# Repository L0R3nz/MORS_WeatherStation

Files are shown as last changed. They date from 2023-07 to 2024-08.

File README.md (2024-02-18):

# M.O.R.S.
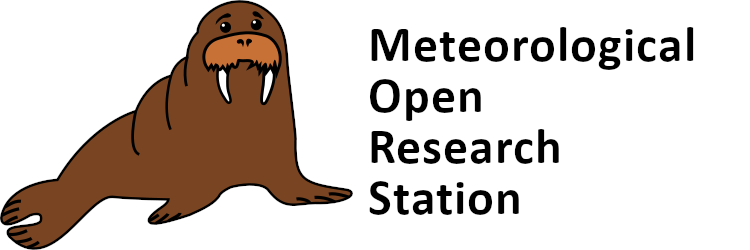
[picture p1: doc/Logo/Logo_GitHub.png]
M.O.R.S.


This weather station is a passion-driven open-source project aimed at providing accurate monitoring of atmospheric conditions. Please note that as a hobby project, it may contain errors or limitations in functionality. However, I will do my best to continuously improving and refining the station's capabilities.

# Links
1. [Project Requirements](doc/Requirements.md)
2. [Sensors Evaluation](doc/Sensors.md)
3. [Hardware Documentation](doc/Hardware.md)

______________________________________________________
M.O.R.S project is based on opensource [tools](doc/Tools.md)

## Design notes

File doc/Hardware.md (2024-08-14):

# Hardware
## 1. EnvironmentSensors
### Jumper list
|Jumper	|Function																	|
|---|---|
|JP1	|Set BME680 Address <br>0x76 - Open <br>0x77 - Closed						|
|JP2	|Set LPS22HB Address <br>0x5C - Open <br>0x5D - Closed						|
|JP3	|Bridge EXT_3V3 signal from connector J1 <br>to 3V3 signal of J2 connector	|

### Useful Files
- [iBom File](/../master/Hardware/1.EnvironmentSensors/Kicad/doc/ibom/) - interactive file which help you while soldering 
- [Schematic File](/../master/Hardware/1.EnvironmentSensors/Kicad/doc/schematic/EnvironmentSensors.pdf)
- [Stencil Holder](/../master/Hardware/Tools/StencilHolder/)

Front side of PCB
![PCB_KiCad_EnvironmentSensors_Front]

Back side of PCB
![PCB_KiCad_EnvironmentSensors_Back]

Stencil Holder 
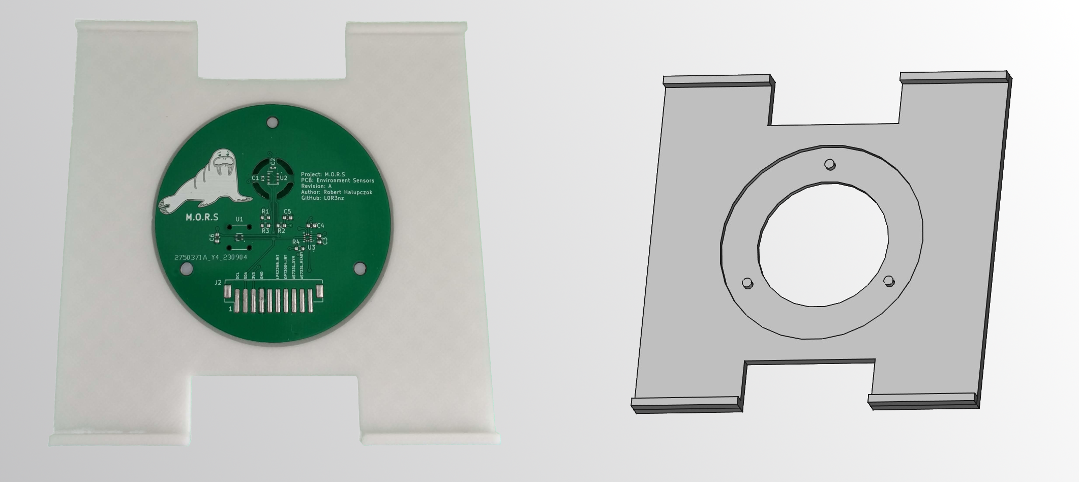
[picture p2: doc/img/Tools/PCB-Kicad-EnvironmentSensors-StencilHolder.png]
PCB_KiCad_EnvironmentSensors_StencilHolder


## 12. LightSensors
### Jumper list
|Jumper	 |Function |
|---|---|
|ADDR1	 |Set OPT3004 Address according to layout description|
|A0 and A1  |Set AS7331 Address according to layout description |

### Useful Files
- [iBom File](/../master/Hardware/2.LightSensors/Kicad/doc/ibom/) - interactive file which help you while soldering 
- [Schematic File](/../master/Hardware/2.LightSensors/Kicad/doc/schematic/LightSensors.pdf)

Front side of PCB
![PCB_KiCad_LightSensors_Front]

Back side of PCB
![PCB_KiCad_LightSensors_Back]

<!-- Images and diagrams -->
[PCB_KiCad_EnvironmentSensors_Front]: 	        img/Hardware/PCB-Kicad-EnvironmentSensors-Front.png
[PCB_KiCad_EnvironmentSensors_Back]: 	        img/Hardware/PCB-Kicad-EnvironmentSensors-Back.png
[PCB_KiCad_EnvironmentSensors_StencilHolder]: 	img/Tools/PCB-Kicad-EnvironmentSensors-StencilHolder.png
[PCB_KiCad_LightSensors_Front]: 	            img/Hardware/PCB-Kicad-LightSensors-Front.png
[PCB_KiCad_LightSensors_Back]: 	                img/Hardware/PCB-Kicad-LightSensors-Back.png

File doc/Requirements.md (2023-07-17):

# Weather Station Project Requirements

The following are the general requirements for the weather station project:

1. The weather station should be designed as an open-source project, allowing for continuous development, customization of functionalities, and integration with other systems.
2. All components used in the weather station should be easily accessible and available for ordinary users to order.
3. The station should be designed with durability and weather resistance in mind, enabling long-term and reliable outdoor use.

## Sensors Requirements

The weather station should accurately measure the following parameters within their specified ranges:

| |Parameter |Unit  |Range |
|:--|:---|:-----|:---|
|1  |Temperature |°C |-40 to 60 |
|2  |Humidity |%RH |0 - 100 |
|3  |Pressure |hPa |800 - 1100|
|4  |Wind Speed |m/s |0 - 50 |
|5  |Wind Direction |rad |0 - 360 |
|6  |Rain Gauge |mm/m² |0 - 100 |
|7  |UV (A/B/C) |μW/cm²|n/a |
|8  |Ambient Light |lux |0 - 200k  |
|9  |Air Quality (PM1 / PM2.5 / PM10) |μg/m³ |0 - 1000  |

## Hardware Requirements

The weather station's hardware should meet the following requirements:

1. Processor and Power Management:
   - The device should be equipped with an energy-efficient processor or microcontroller that enables efficient power management.
   - The power management system should be optimized for minimal energy consumption, allowing for long-term operation on batteries or efficient utilization of available power sources.

2. Wireless Communication:
   - Wireless communication modules such as Wi-Fi, Bluetooth, or LoRa should be optimized for low energy consumption, enabling efficient data transmission with minimal impact on power resources.
   - The device should incorporate power management features for adjusting the transmission frequency and power as needed.

3. Sensors:
   - The selection of sensors should prioritize low energy consumption to minimize the impact on device energy efficiency.
   - Sensors with features like automatic wake-up or energy regulation should be preferred to activate them only when necessary.

4. Power Resource Management:
   - The device should have intelligent power resource management mechanisms, such as sleep mode or automatic shut-off of unused components, to minimize energy consumption during idle periods.
   - The software should include energy optimization algorithms to efficiently utilize power resources in different operational scenarios.

## Enclosure Requirements

The enclosure of the weather station should meet the following specifications:

1. The enclosure should be made of durable and weather-resistant material.
2. It should be sealed to provide protection against moisture, dust, and sun radiation.
3. All enclosure components, including structural elements and fittings, should be 3D-printable for cost-effective manufacturing and customization.

## Additional Requirements

1. The weather station should be designed for future integration with photovoltaic (PV) panels for power supply, though this functionality will not be implemented initially.
2. Remote software updates should be possible to facilitate easy enhancements and bug fixes.

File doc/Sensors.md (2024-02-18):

# Sensor Evaluation 

In following document you will find information regarding sensor planned to use in weather station project.
___

For more accurate results, I plan to use multiple sensors for temperature, humidity, and pressure. All of these sensors will be located on separate PCBs to mitigate the influence of other circuit elements that can generate heat and thereby interfere with the measurements. This sensor board should be located in solar radiation shield to minimize direct sunlight which can heat up the sensors, affecting the accuracy of temperature readings

# Sensors Diagram
SensorDiagram

## 1. Environment Sensors Group

|Sensor |[BME680](Datasheets/BME680.pdf) |[SHT45](Datasheets/SHT4x.pdf)  |[LPS22HB](Datasheets/LPS22HB.pdf)|
|---|---|---|---|
|Temperature |:white_check_mark: |:white_check_mark: |:x: |
|Humidity |:white_check_mark: |:white_check_mark: |:x: |
|Pressure |:white_check_mark: |:x: |:white_check_mark: |
|SPI |:white_check_mark: |:x: |:white_check_mark: |
|I2C |:white_check_mark: |:white_check_mark: |:white_check_mark: |
|Voltage |1.71 - 3.6 |1.08 - 3.6 |1.70 - 3.6 |
|Current Consumption  |12 mA (Active)<br>1 mA (Low Power)<br>90 μA (Ultra Low Power)|2 μA (Average) |3 μA (Average) |

## 2. Light Sensors Group

|Sensor |[AS7331](Datasheets/AS7331.pdf) |[OPT3004](Datasheets/OPT3004.pdf) |
|---|---|---|
|UV (A/B/C) |:white_check_mark: |:x: |
|Ambient Light |:x: |:white_check_mark: |
|SPI |:x: |:x: |
|I2C |:white_check_mark: |:white_check_mark: |
|Voltage |2.7 - 3.6 |1.6 - 3.6
|Current Consumption  |2 mA (Active)<br>970 μA (Standby)<br>1 μA (Power Down) |1.8 μA (Typical)

<!-- ## 3. Wind Sensors Group -->
<!-- ## 4. Rain Sensor Group -->

<!-- Images and diagrams -->
[SensorDiagram]: img/Sensors/Sensors-diagram.svg

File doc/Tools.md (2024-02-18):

# Tools used in project
## [KiCad](https://www.kicad.org/)
```
Application: KiCad x64 on x64

Version: 7.0.6, release build

Libraries:
	wxWidgets 3.2.2
	FreeType 2.12.1
	HarfBuzz 6.0.0
	FontConfig 2.14.1
	libcurl/7.88.1-DEV Schannel zlib/1.2.13

Platform: Windows 10 (build 19045), 64-bit edition, 64 bit, Little endian, wxMSW

Build Info:
	Date: Jul  6 2023 04:56:45
	wxWidgets: 3.2.2 (wchar_t,wx containers)
	Boost: 1.81.0
	OCC: 7.6.3
	Curl: 7.88.1-DEV
	ngspice: 40
	Compiler: Visual C++ 1936 without C++ ABI

Build settings:
	KICAD_SPICE=ON
```
### Installed addons:

|Addon |Version |
|---|---|
|__Espressif KiCad Library__ |[2.0.1](https://github.com/espressif/kicad-libraries/releases/tag/2.0.1) |
|__Fabrication Toolkit__ |[3.0.0](https://github.com/bennymeg/JLC-Plugin-for-KiCad/releases/tag/3.0.0) |
|__Interactive Html Bom__ |[2.7.0](https://github.com/openscopeproject/InteractiveHtmlBom/releases/tag/v2.7.0)|
|__Archive 3D Models__ |[1.0.10](https://github.com/MitjaNemec/Archive3DModels/releases/tag/1.0.10) |

## [FreeCad](https://www.freecad.org/)
```
OS: Windows 10 Version 2009
Word size of FreeCAD: 64-bit
Version: 0.20.2.29603 (Git)
Build type: Release
Branch: releases/FreeCAD-0-20
Hash: 930dd9a76203a3260b1e6256c70c1c3cad8c5cb8
Python 3.8.10, Qt 5.15.2, Coin 4.0.1, Vtk 8.2.0, OCC 7.6.3
Locale: Polish/Poland (pl_PL)
Installed mods: 
  * A2plus 0.4.60n
  * kicadStepUpMod 10.19.4
```

## [Inkscape](https://inkscape.org/)
```
Inkscape 1.2.2 (732a01da63, 2022-12-09)
```

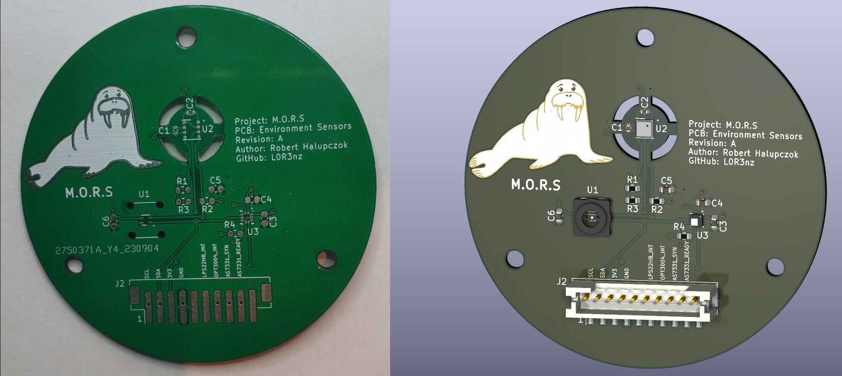
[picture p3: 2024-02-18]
doc/img/Hardware/PCB-Kicad-EnvironmentSensors-Front.png

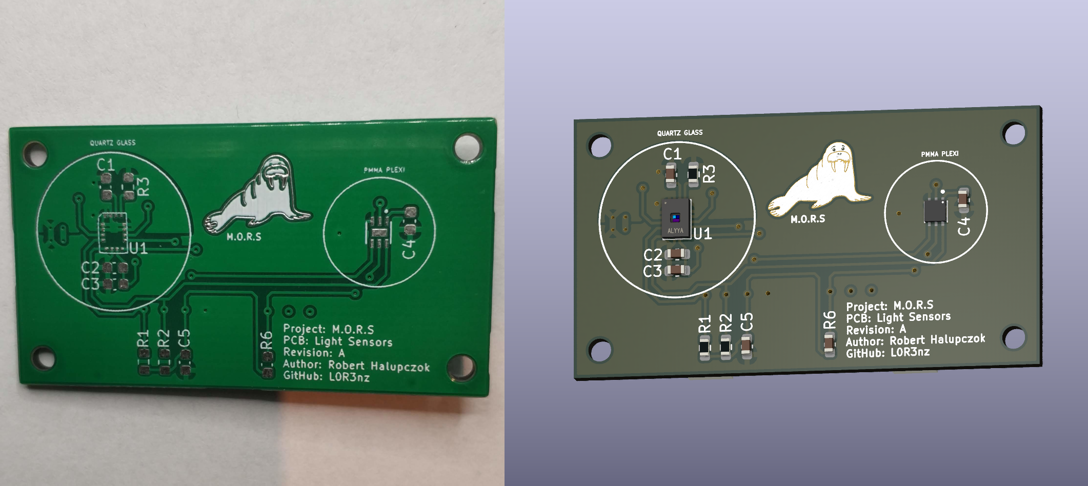
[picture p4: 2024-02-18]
doc/img/Hardware/PCB-Kicad-LightSensors-Front.png

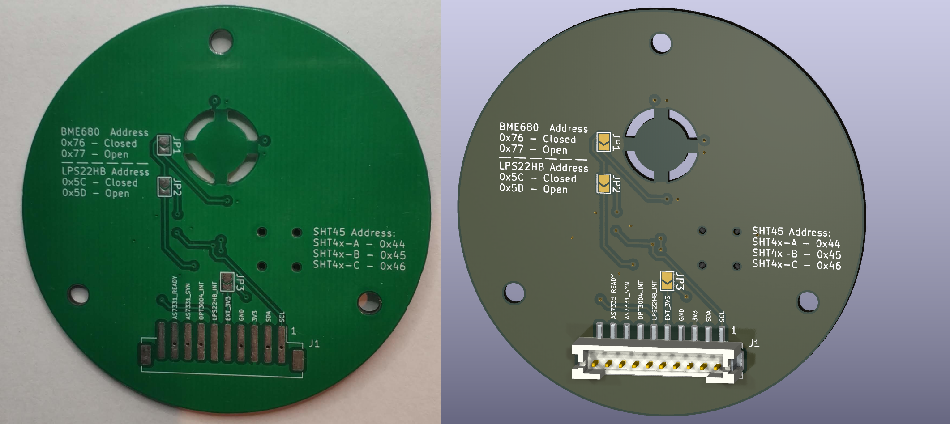
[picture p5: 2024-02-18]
doc/img/Hardware/PCB-Kicad-EnvironmentSensors-Back.png

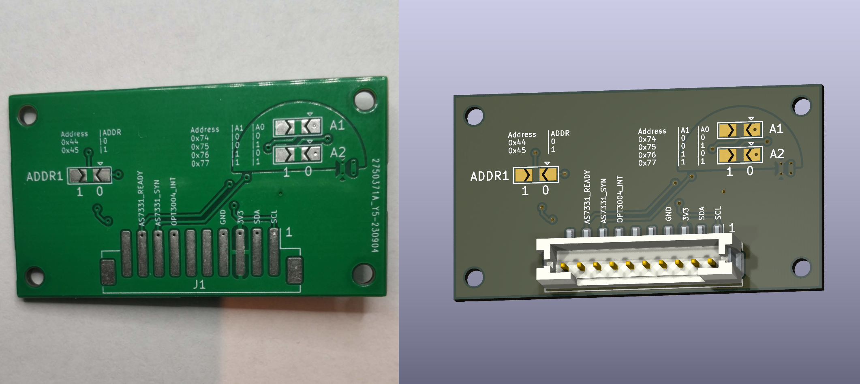
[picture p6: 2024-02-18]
doc/img/Hardware/PCB-Kicad-LightSensors-Back.png

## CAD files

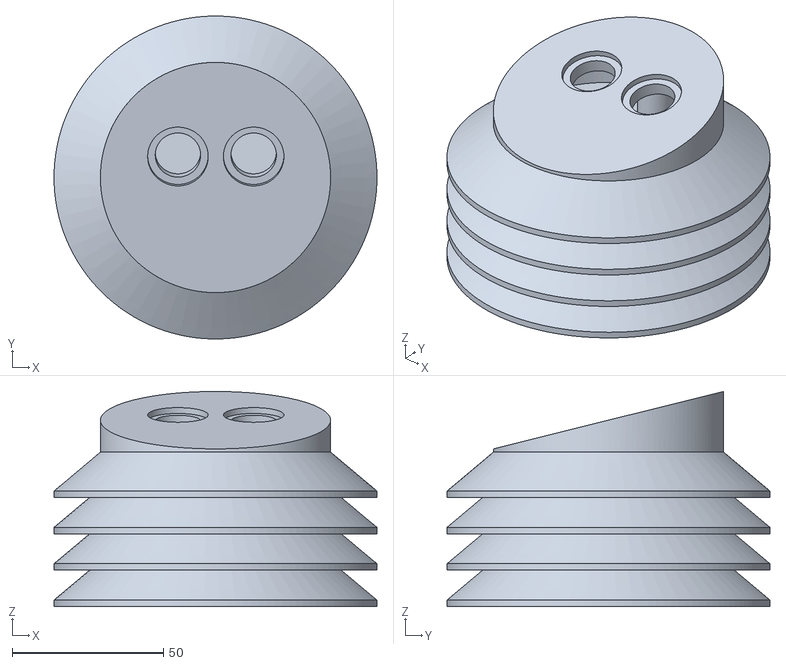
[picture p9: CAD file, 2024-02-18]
Hardware/1.EnvironmentSensors/RadiationShield/3dModels/RadiationShield_Assembly-Part.stl
106.6 x 106.6 x 71.0

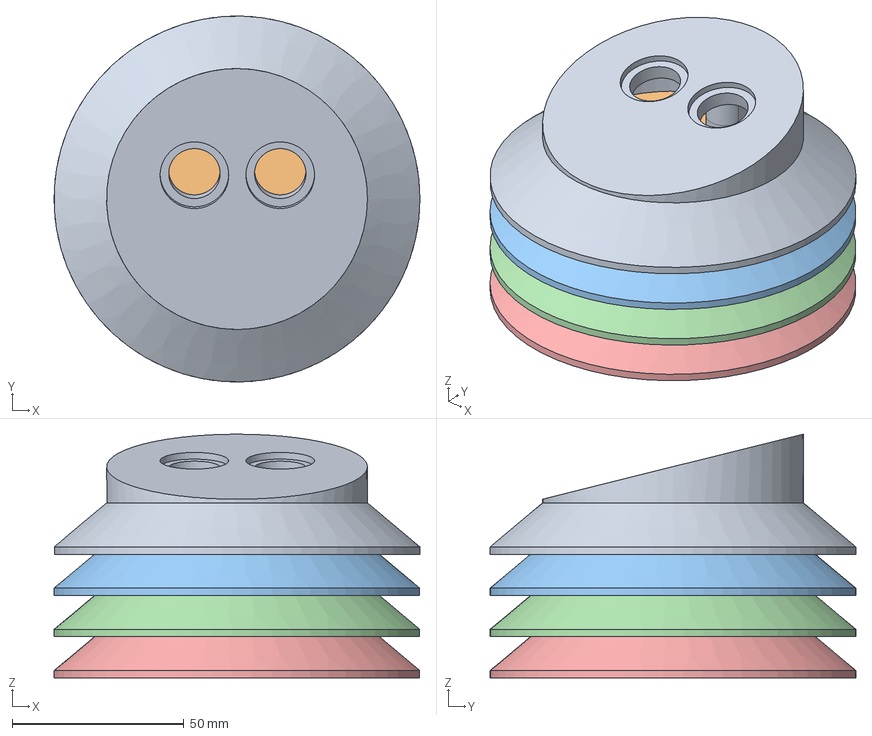
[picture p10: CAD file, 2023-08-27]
Hardware/1.EnvironmentSensors/RadiationShield/RadiationShield_Assembly.FCStd
106.6 x 106.6 x 71.0 mm
RadiationShield_TopSection_Body_001
RadiationShield_TopSection_Back_Body_001
RadiationShield_InnerSection_Body_001
RadiationShield_PCB_Section_Body_001
RadiationShield_InnerSection_Body_002
Insert M2 D3.6 L4mm1_001
Insert M2 D3.6 L4mm1_002
Insert M2 D3.6 L4mm1_003
Insert M2 D3.6 L4mm1_004
Insert M3 D4.2 L5mm1_001
Insert M3 D4.2 L5mm1_002
Insert M3 D4.2 L5mm1_003

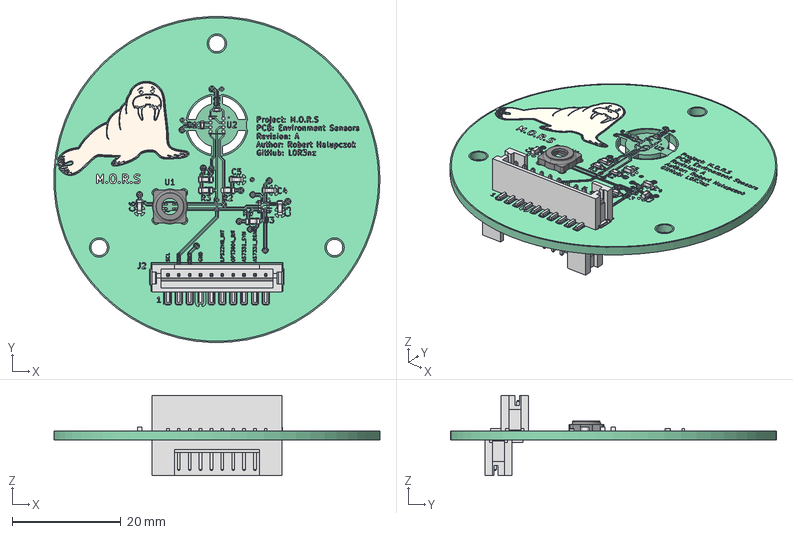
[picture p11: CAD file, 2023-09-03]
Hardware/1.EnvironmentSensors/PCB 3D Model/FreeCAD_PCB_EnvironmentSensors.FCStd
60.0 x 60.0 x 14.8 mm
Pcb_109c
botSilks_6977
topSilks_64a3
topPads_109c_cut
topTracks_109c
topZones_109c
botPads_109c
botTracks_109c
botZones_109c
FL1_SF2 FILTER CAP_ae273ac61228
J2_B10B-PH-SM4-TB_3234bc85b0de x 2
C5_C_0603_1608Metric_abbc689fc792 x 4
C2_C_0402_1005Metric_dd3df2a8d971 x 2
R3_R_0603_1608Metric_a70520763359 x 4

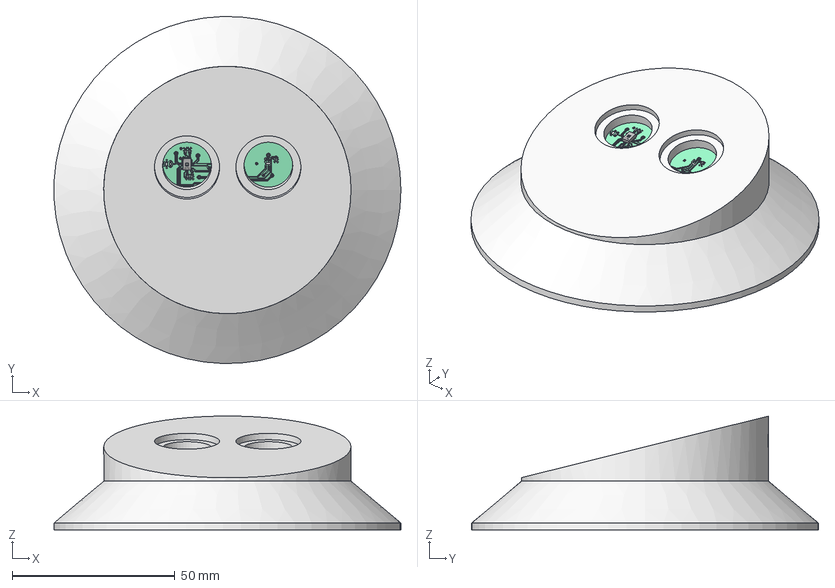
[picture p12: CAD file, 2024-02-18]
Hardware/1.EnvironmentSensors/RadiationShield/RadiationShield_TopSection.FCStd
106.6 x 106.6 x 35.0 mm
Pcb_d046
topPads_d046_cut
topTracks_d046
topZones_d046
botPads_d046
botTracks_d046
botZones_d046
C4_C_0402_1005Metric_b3a6d92d001c x 4
U1_AS7331-OLGA-16_3cea2e175b30
R2_R_0402_1005Metric_fd135c15df6e x 4
J1_B10B-PH-SM4-TB_0caca42d7e3f[2]

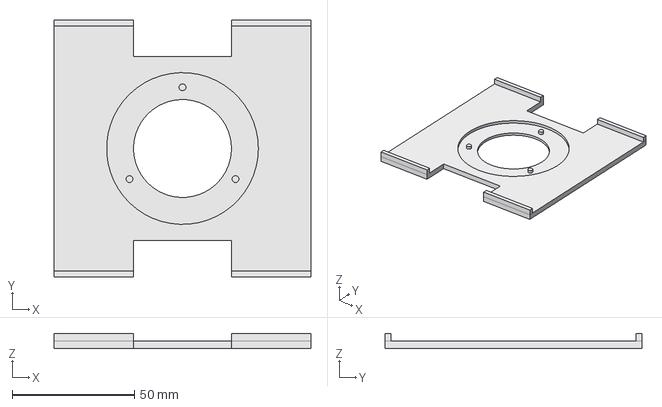
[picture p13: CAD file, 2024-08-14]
Hardware/1.EnvironmentSensors/Tools/StencilHolder/EnvironmentSensors_ Stencil_Holder.FCStd
105.0 x 105.0 x 6.00 mm

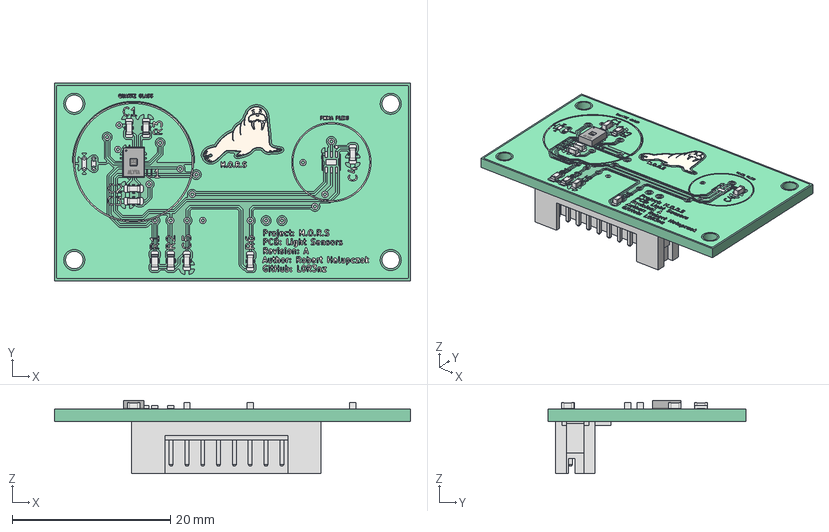
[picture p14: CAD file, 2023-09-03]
Hardware/2.LightSensors/PCB 3D Model/FreeCAD_PCB_LightSensors.FCStd
45.0 x 25.0 x 9.29 mm
Pcb_d046
botSilks_dbf4
topSilks_d620
topPads_d046_cut
topTracks_d046
topZones_d046
botPads_d046
botTracks_d046
botZones_d046
C5_C_0603_1608Metric_437663a5777d x 6
U1_AS7331-OLGA-16_3cea2e175b30
R2_R_0603_1608Metric_fd135c15df6e x 3
J1_B10B-PH-SM4-TB_0caca42d7e3f

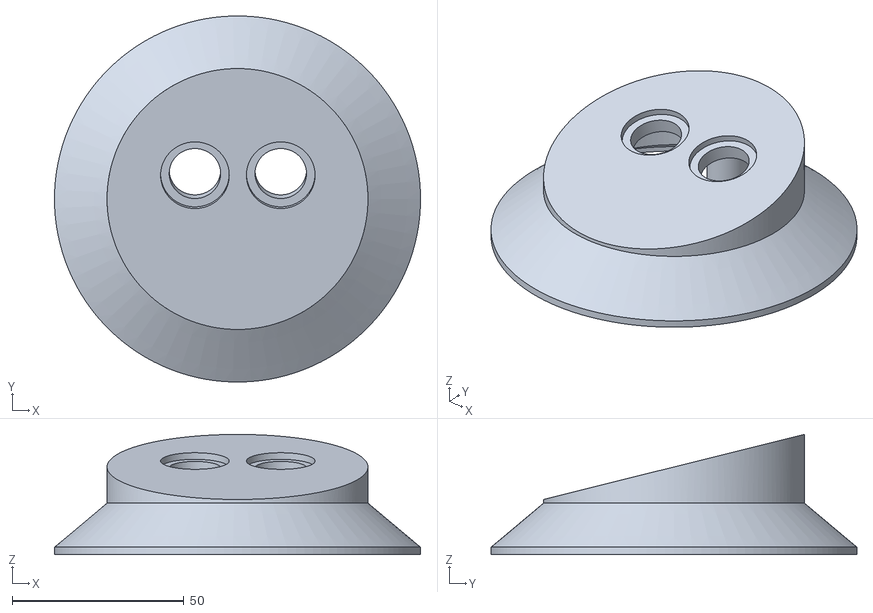
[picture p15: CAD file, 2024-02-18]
Hardware/1.EnvironmentSensors/RadiationShield/3dModels/RadiationShield_TopSection-Body.stl
106.6 x 106.6 x 35.0

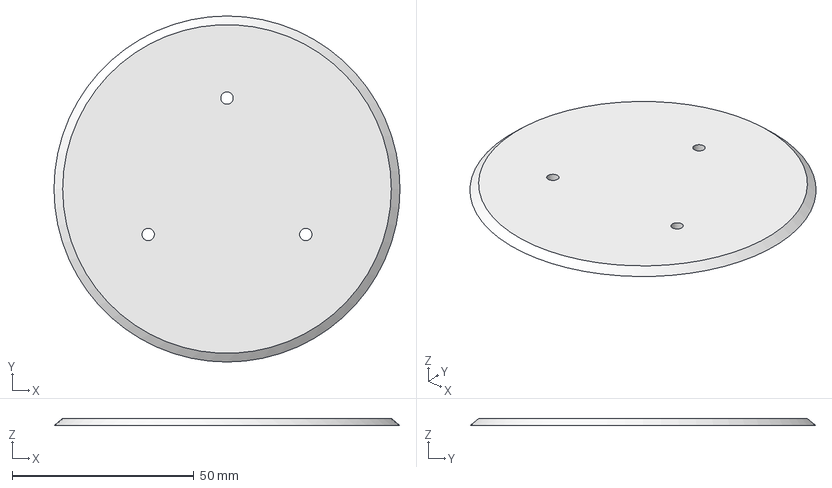
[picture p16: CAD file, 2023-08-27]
Hardware/1.EnvironmentSensors/RadiationShield/RadiationShield_TopSection_Back.FCStd
95.1 x 95.1 x 2.00 mm

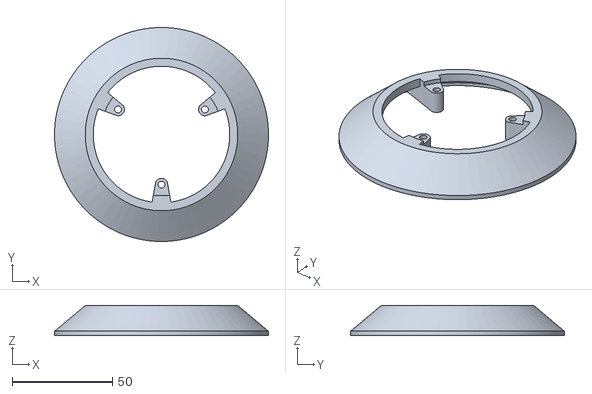
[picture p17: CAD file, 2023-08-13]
Hardware/1.EnvironmentSensors/RadiationShield/3dModels/RadiationShield_PCB_Section-Body.stl
106.6 x 106.6 x 15.0

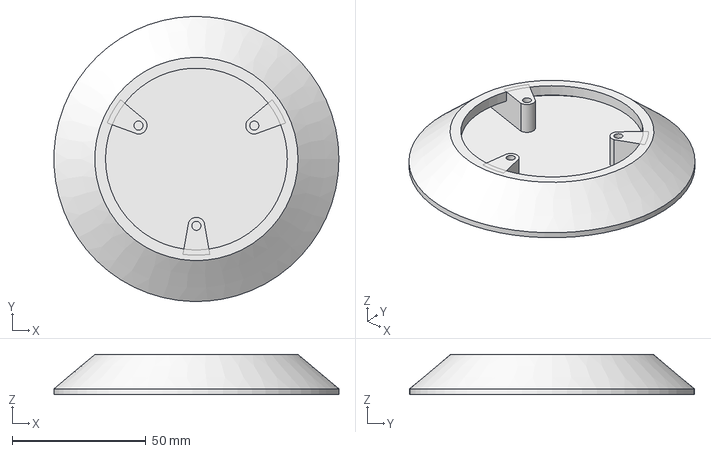
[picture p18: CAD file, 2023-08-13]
Hardware/1.EnvironmentSensors/RadiationShield/RadiationShield_BottomSection.FCStd
106.6 x 106.6 x 15.0 mm

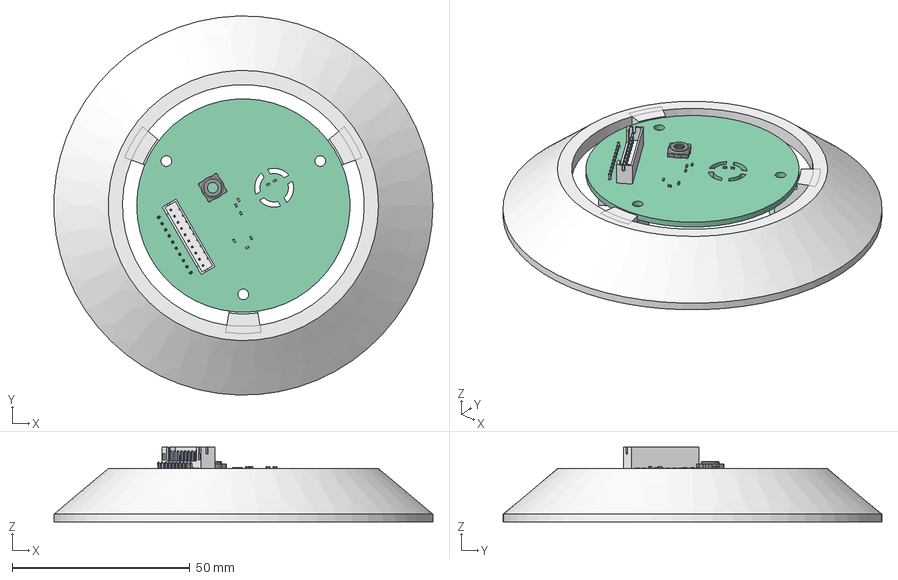
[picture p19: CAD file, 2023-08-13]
Hardware/1.EnvironmentSensors/RadiationShield/RadiationShield_PCB_Section.FCStd
106.6 x 106.6 x 21.0 mm
Pcb_109c
FL1_SF2 FILTER CAP_ae273ac61228
J2_JST_B10B_PH_K_3234bc85b0de x 2
C4_C_0402_1005Metric_3347db99f0d9 x 4
R3_R_0402_1005Metric_a70520763359 x 4

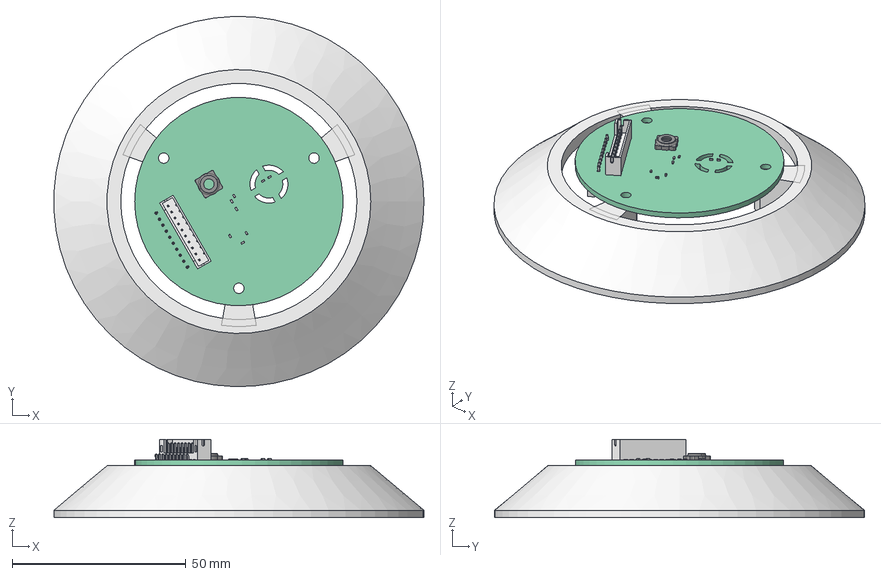
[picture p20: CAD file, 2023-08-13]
Hardware/1.EnvironmentSensors/RadiationShield/RadiationShield_InnerSection.FCStd
106.6 x 106.6 x 22.6 mm
Pcb_109c
FL1_SF2 FILTER CAP_ae273ac61228
J2_JST_B10B_PH_K_3234bc85b0de x 2
C4_C_0402_1005Metric_3347db99f0d9 x 4
R3_R_0402_1005Metric_a70520763359 x 4

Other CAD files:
Hardware/1.EnvironmentSensors/Tools/StencilHolder/EnvironmentSensors_ Stencil_Holder-Body.stl
Hardware/1.EnvironmentSensors/RadiationShield/3dModels/RadiationShield_TopSection_Back-Body.stl
Hardware/1.EnvironmentSensors/RadiationShield/3dModels/RadiationShield_BottomSection-Body.stl
Hardware/1.EnvironmentSensors/RadiationShield/3dModels/RadiationShield_InnerSection-Body.stl
Hardware/1.EnvironmentSensors/PCB 3D Model/3d_models/FreeCAD_PCB_EnvironmentSensors.stl
Hardware/2.LightSensors/PCB 3D Model/3d_models/FreeCAD_PCB_LightSensors.stl

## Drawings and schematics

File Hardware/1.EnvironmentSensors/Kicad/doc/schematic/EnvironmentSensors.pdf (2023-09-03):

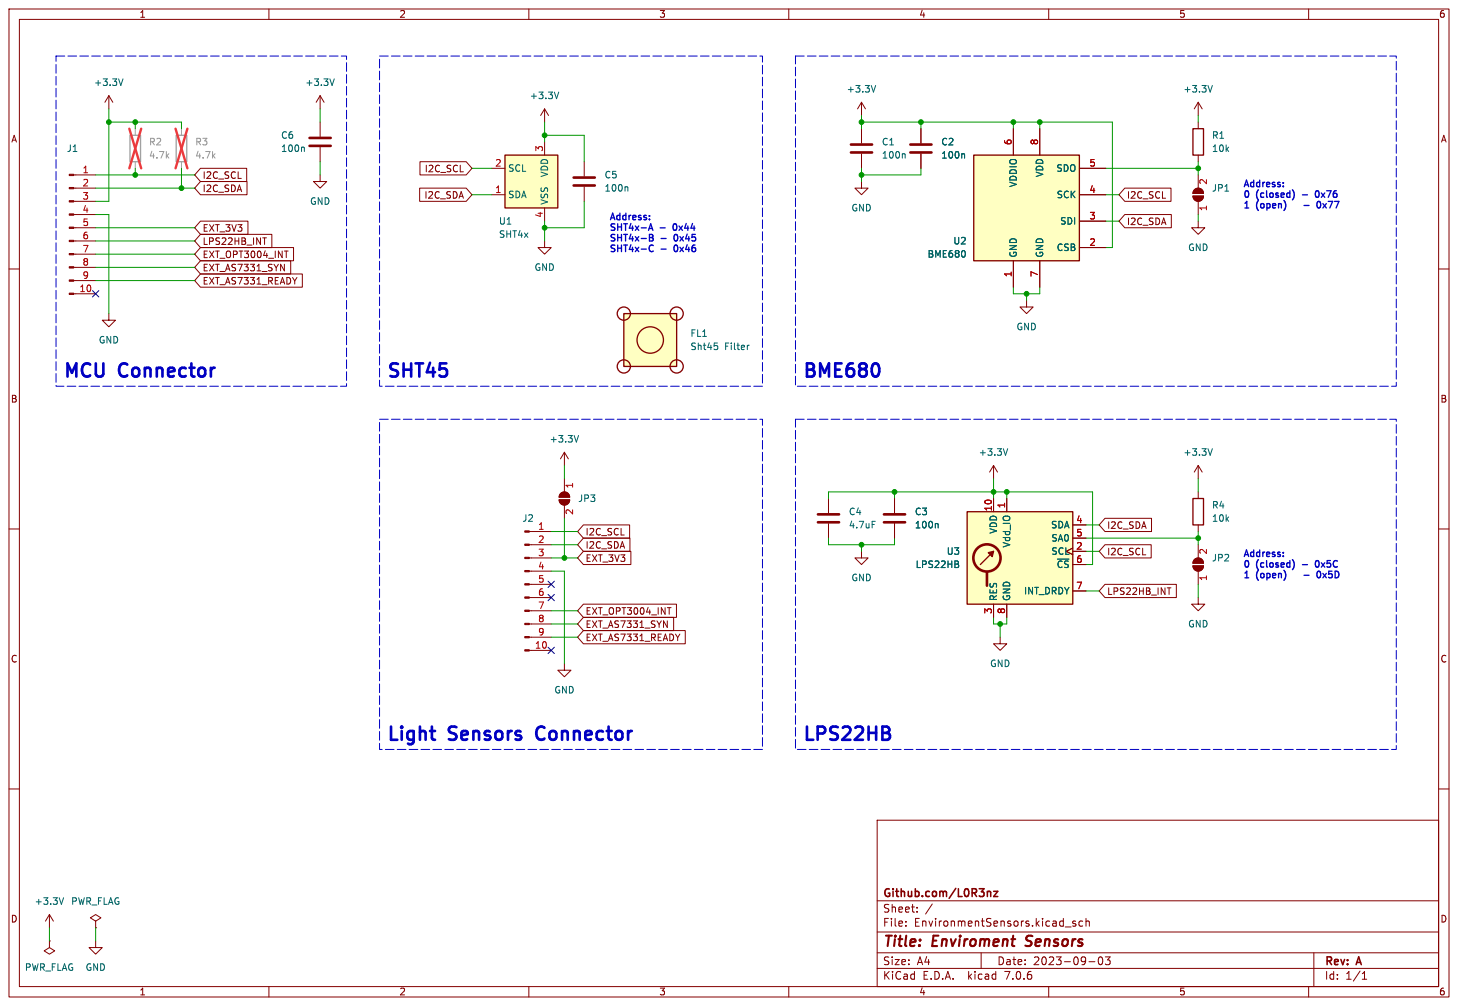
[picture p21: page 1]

1 CSB 2 SDI 3 SCK 4 SDO 5 VDDIO

File: EnvironmentSensors.kicad_sch Sheet: / Github.com/L0R3nz

Id: 1/1 Title: Enviroment Sensors

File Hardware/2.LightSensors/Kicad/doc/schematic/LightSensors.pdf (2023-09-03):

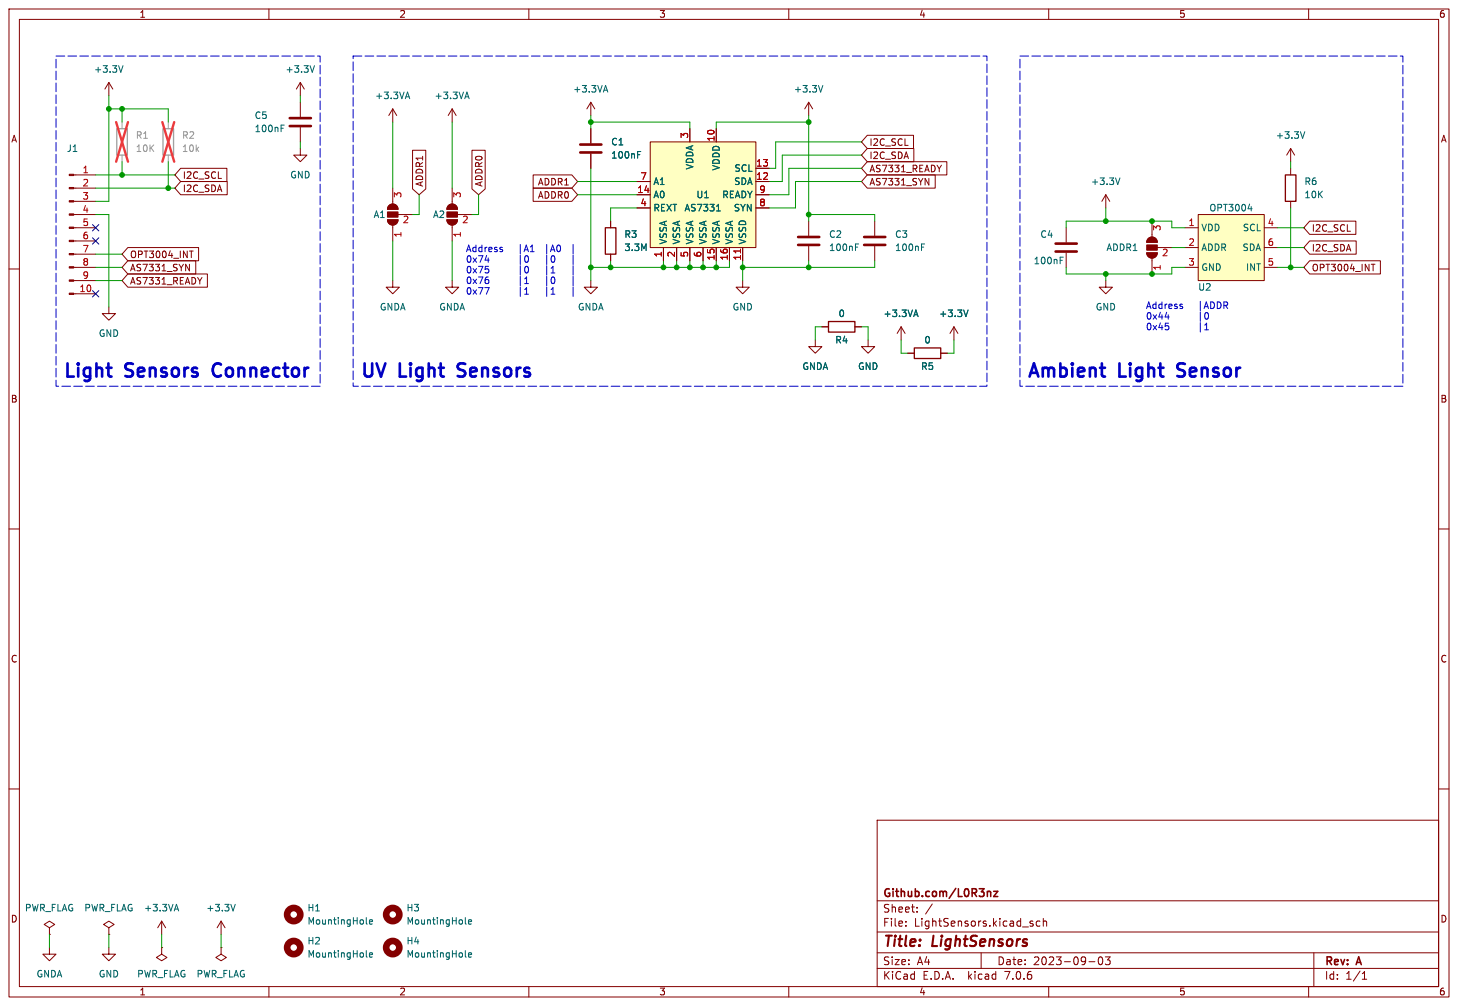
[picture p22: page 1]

1 VDDD 10 VSSD 11 SDA 12 SCL 13 A0 14 VSSA 15 VSSA 16 VSSA

File: LightSensors.kicad_sch Sheet: / Github.com/L0R3nz

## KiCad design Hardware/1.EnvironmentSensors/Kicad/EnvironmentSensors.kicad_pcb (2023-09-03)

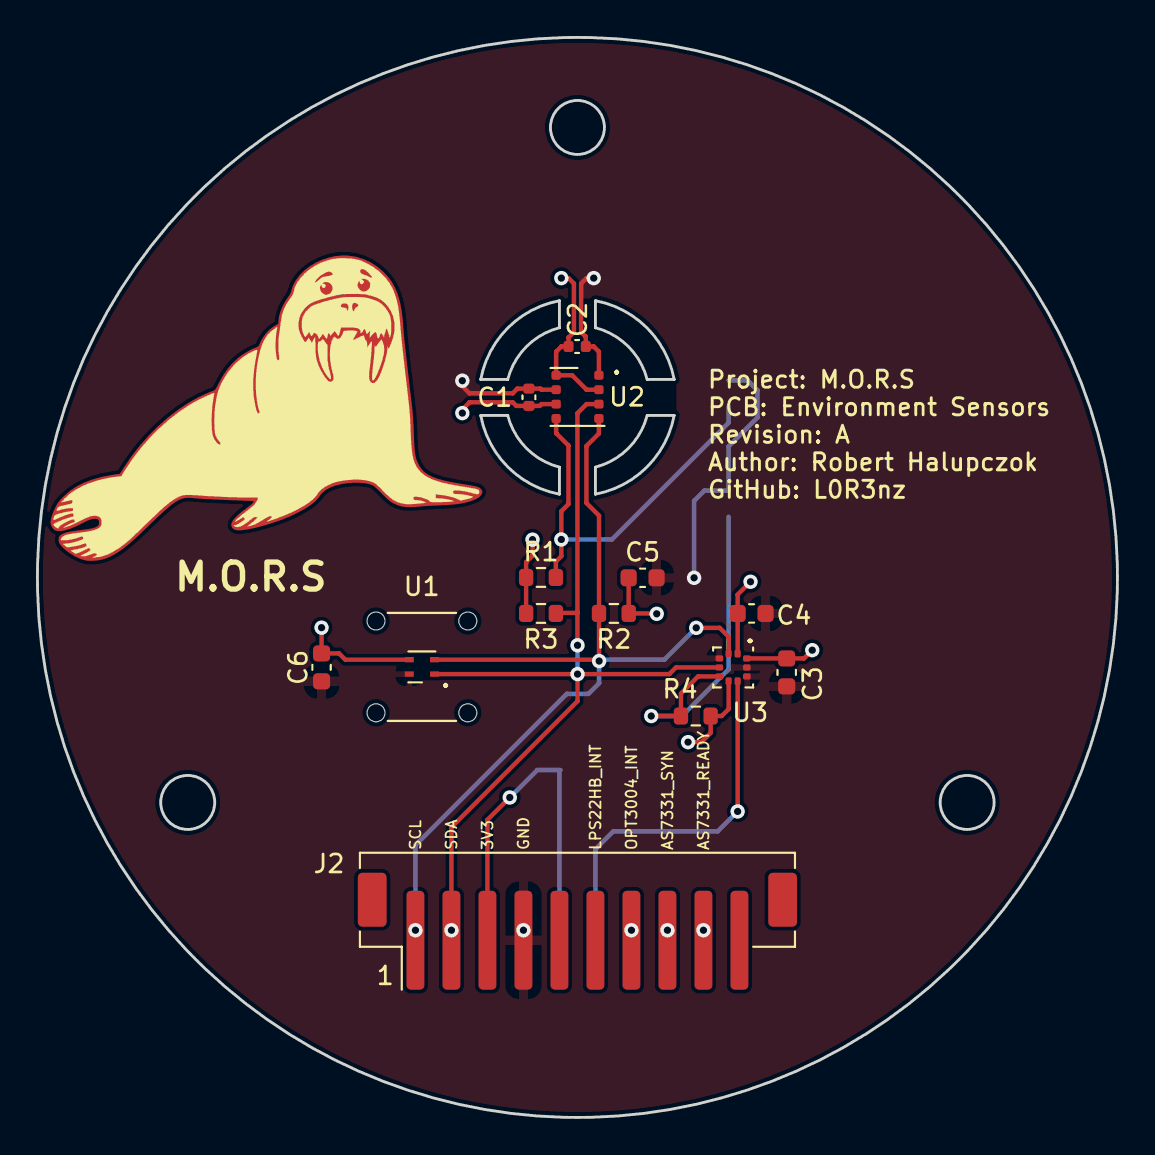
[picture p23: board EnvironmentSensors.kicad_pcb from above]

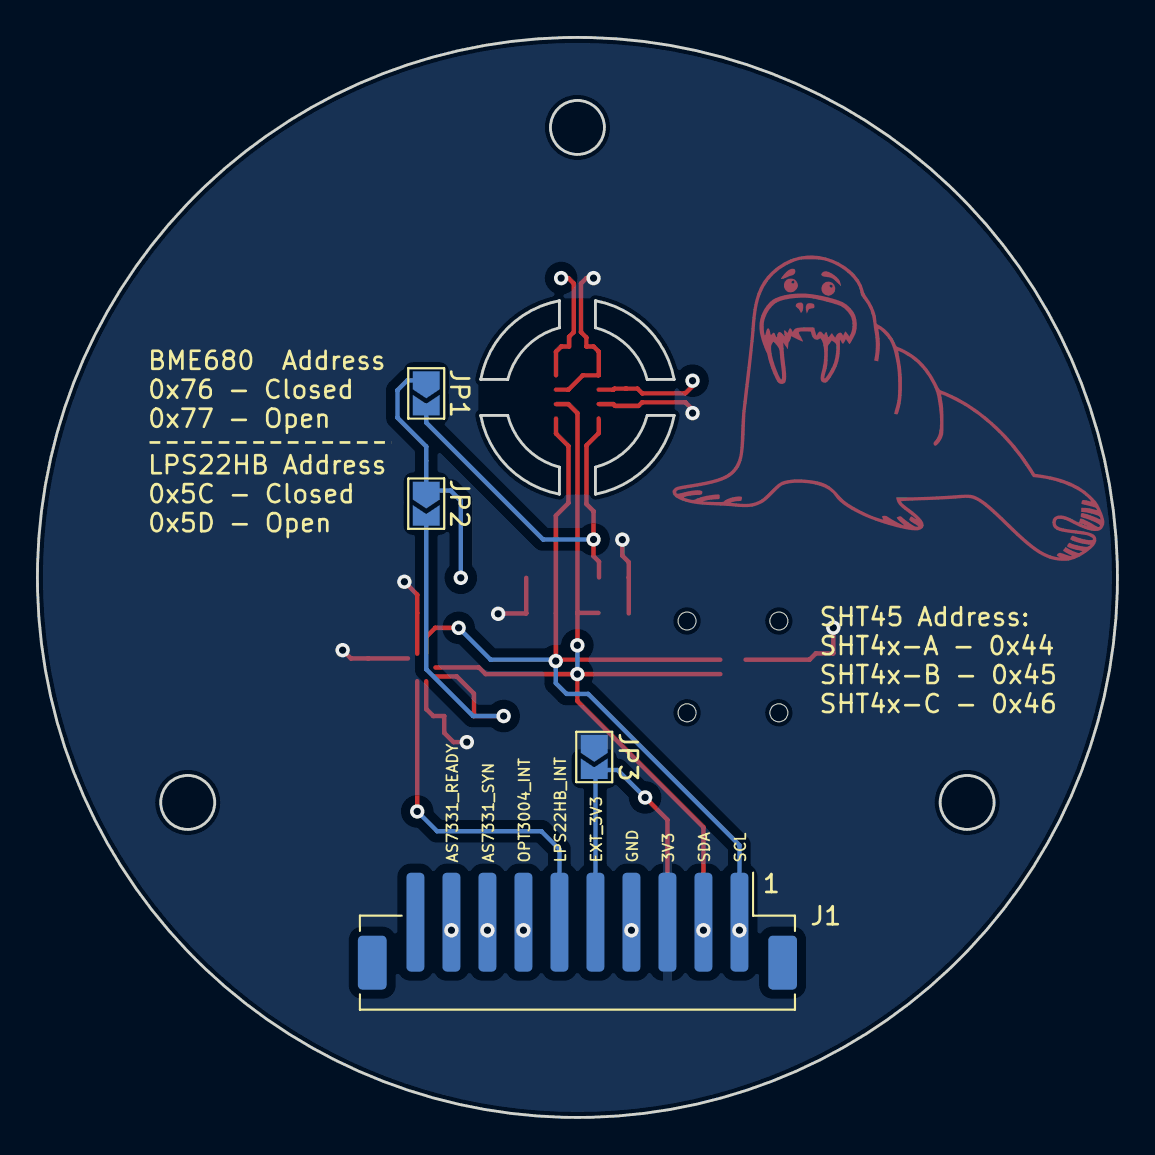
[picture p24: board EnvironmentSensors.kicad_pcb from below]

Board: 2 copper layers, 60.0 x 60.0 mm, 19 parts (4 on the bottom side), 11 nets.

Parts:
C1, C2: 100n; C_0402_1005Metric
C3, C5, C6: 100n; C_0603_1608Metric
C4: 4.7uF; C_0603_1608Metric
FL1: Sht45 Filter; FIL_SF2_FILTER_CAP
J1, J2: Conn_01x10_Pin; JST_PH_B10B-PH-SM4-TB_1x10-1MP_P2.00mm_Vertical
JP1, JP2, JP3: SolderJumper_2_Open; SolderJumper-2_P1.3mm_Open_TrianglePad1.0x1.5mm
R1, R4: 10k; R_0603_1608Metric
R2, R3: 4.7k; R_0603_1608Metric
U1: SHT4x; Sensirion_DFN-4_1.5x1.5mm_P0.8mm_SHT4x_NoCentralPad
U2: BME680; Bosch_LGA-8_3x3mm_P0.8mm_ClockwisePinNumbering
U3: LPS22HB; ST_HLGA-10_2x2mm_P0.5mm_LayoutBorder3x2y

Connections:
+3.3V: C1.1, C2.1, C3.1, C4.1, C5.1, C6.1, J1.3, JP3.1 (A), R1.1, R2.1, R3.2, R4.1, U1.3 (VDD), U2.2 (CSB), U2.6 (VDDIO), U2.8 (VDD), U3.1 (Vdd_IO), U3.6 (~CS), U3.10 (VDD)
EXT_3V3: J1.5, J2.3, JP3.2 (B)
EXT_AS7331_READY: J1.9, J2.9
EXT_AS7331_SYN: J1.8, J2.8
EXT_OPT3004_INT: J1.7, J2.7
GND: C1.2, C2.2, C3.2, C4.2, C5.2, C6.2, J1.4, J2.4, JP1.1 (A), JP2.1 (A), U1.4 (VSS), U2.1 (GND), U2.7 (GND), U3.3 (RES), U3.8 (GND), U3.9 (GND)
I2C_SCL: J1.1, J2.1, R2.2, U1.2 (SCL), U2.4 (SCK), U3.2 (SCL)
I2C_SDA: J1.2, J2.2, R3.1, U1.1 (SDA), U2.3 (SDI), U3.4 (SDA)
LPS22HB_INT: J1.6, U3.7 (INT_DRDY)
unnamed: JP1.2 (B), R1.2, U2.5 (SDO)
unnamed: JP2.2 (B), R4.2, U3.5 (SA0)

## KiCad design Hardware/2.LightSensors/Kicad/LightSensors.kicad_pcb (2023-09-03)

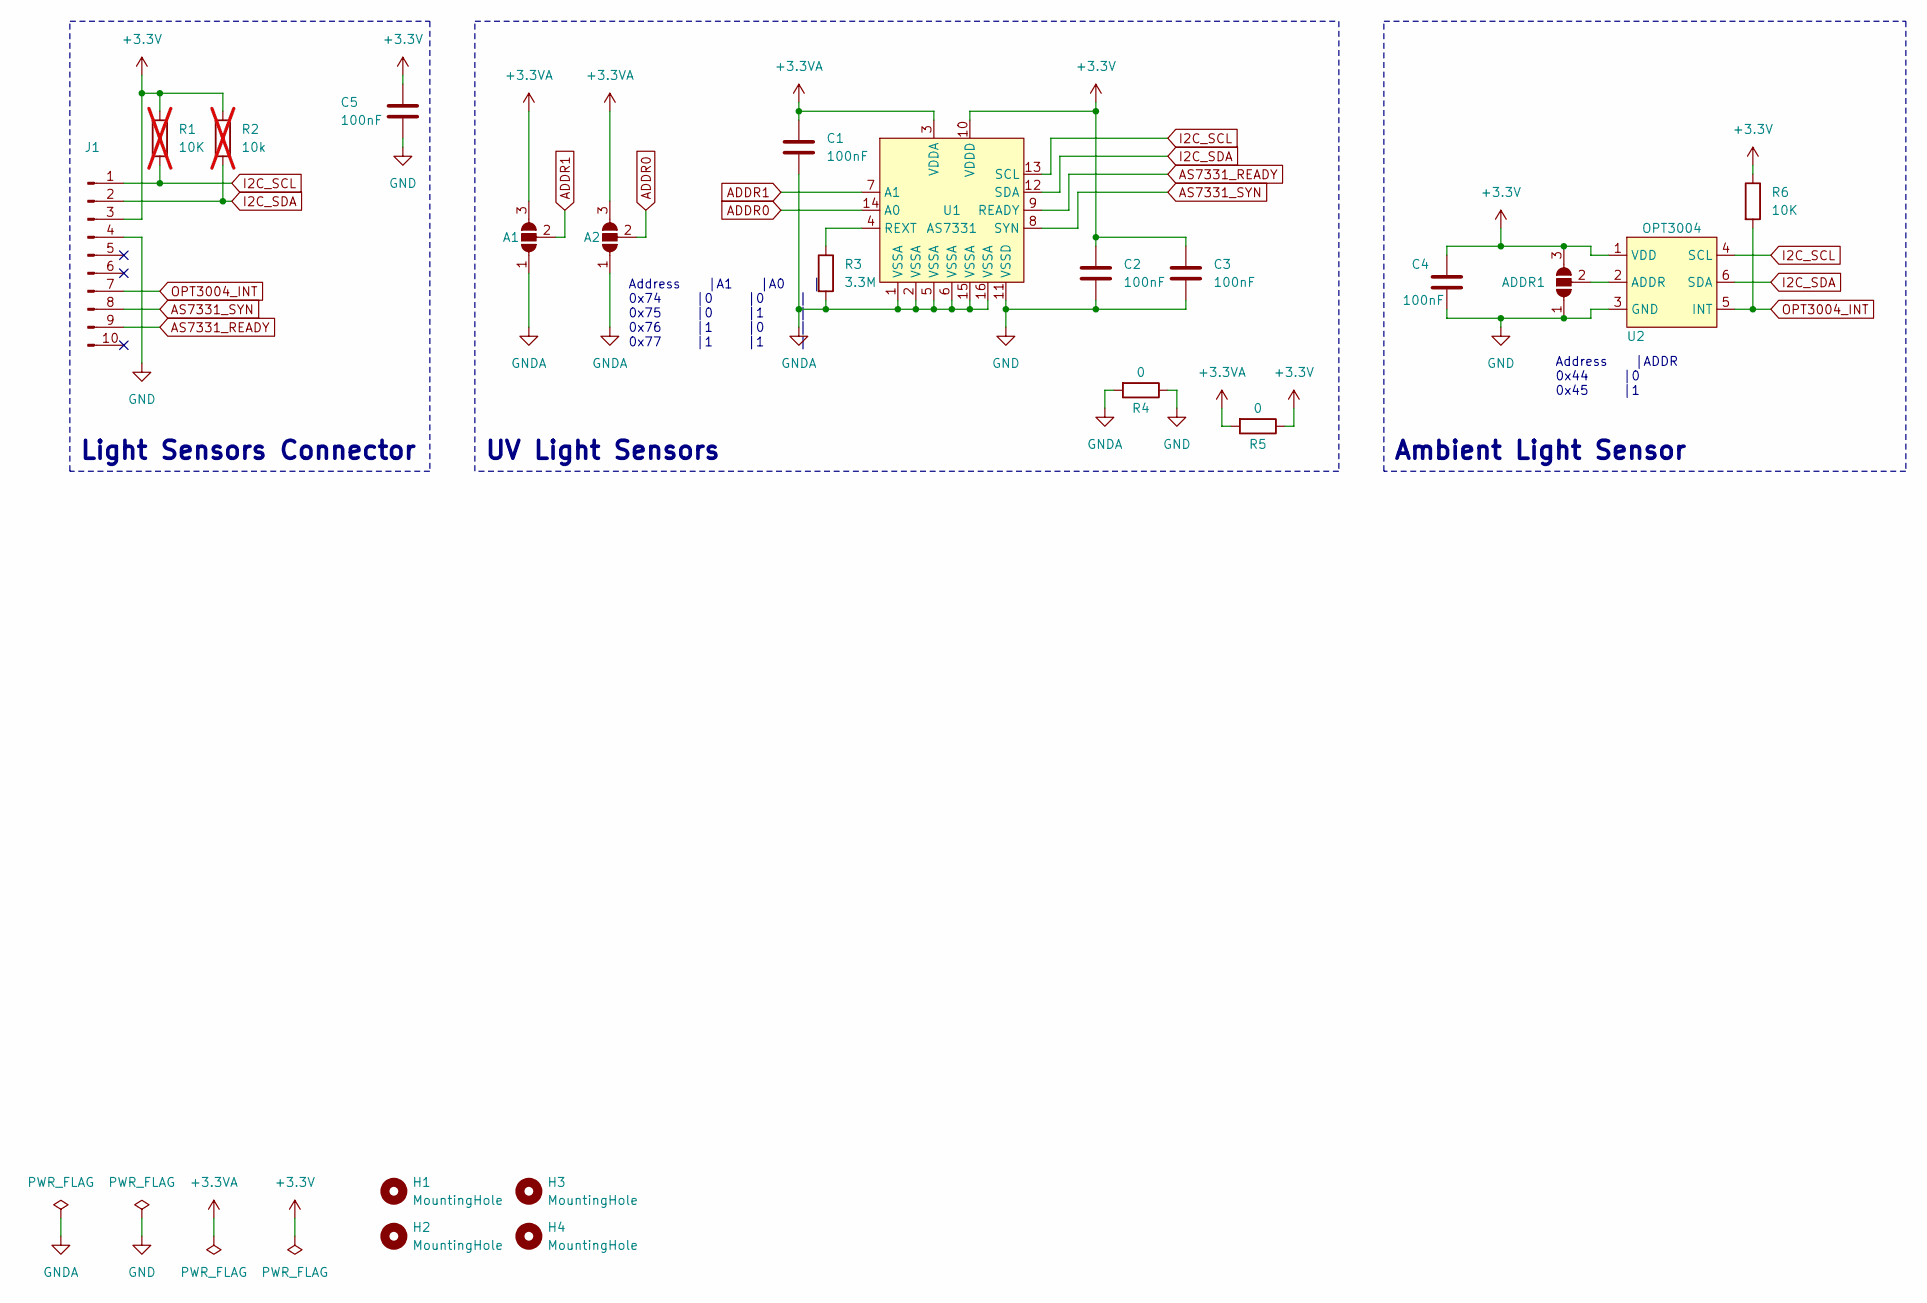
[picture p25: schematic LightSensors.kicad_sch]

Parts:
A1, A2: SolderJumper_3_Open; SolderJumper-3_P2.0mm_Open_TrianglePad1.0x1.5mm
ADDR1: SolderJumper_3_Open; SolderJumper-3_P2.0mm_Open_TrianglePad1.0x1.5mm
C1, C2, C3, C4, C5: 100nF; C_0603_1608Metric
H1, H2, H3, H4: MountingHole; MountingHole_2.2mm_M2
J1: Conn_01x10_Pin; JST_PH_B10B-PH-SM4-TB_1x10-1MP_P2.00mm_Vertical
R1: 10K; R_0603_1608Metric; not fitted
R2: 10k; R_0603_1608Metric; not fitted
R3: 3.3M; R_0603_1608Metric
R4, R5: 0; NetTie-2_THT_Pad0.3mm
R6: 10K; C_0603_1608Metric
U1: AS7331; OLGA-16
U2: OPT3004; SON65P200X200X65-7N

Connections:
+3.3V: ADDR1.3 (B), C2.1, C3.1, C4.1, C5.1, J1.3, R1.1, R2.1, R5.1, R6.1, U1.10 (VDDD), U2.1 (VDD)
+3.3VA: A1.3 (B), A2.3 (B), C1.1, R5.2, U1.3 (VDDA)
ADDR0: A2.2 (C), U1.14 (A0)
ADDR1: A1.2 (C), U1.7 (A1)
AS7331_READY: J1.9, U1.9 (READY)
AS7331_SYN: J1.8, U1.8 (SYN)
GND: ADDR1.1 (A), C2.2, C3.2, C4.2, C5.2, J1.4, R4.1, U1.11 (VSSD), U2.3 (GND)
GNDA: A1.1 (A), A2.1 (A), C1.2, R3.2, R4.2, U1.1 (VSSA), U1.2 (VSSA), U1.5 (VSSA), U1.6 (VSSA), U1.15 (VSSA), U1.16 (VSSA)
I2C_SCL: J1.1, R1.2, U1.13 (SCL), U2.4 (SCL)
I2C_SDA: J1.2, R2.2, U1.12 (SDA), U2.6 (SDA)
unnamed: ADDR1.2 (C), U2.2 (ADDR)
unnamed: R3.1, U1.4 (REXT)
OPT3004_INT: J1.7, R6.2, U2.5 (INT)

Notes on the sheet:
Light Sensors Connector
Address |A1 |A0 | 0x74 |0 |0 | 0x75 |0 |1 | 0x76 |1 |0 | 0x77 |1 |1 |
UV Light Sensors
Ambient Light Sensor
Address |ADDR 0x44 |0 0x45 |1

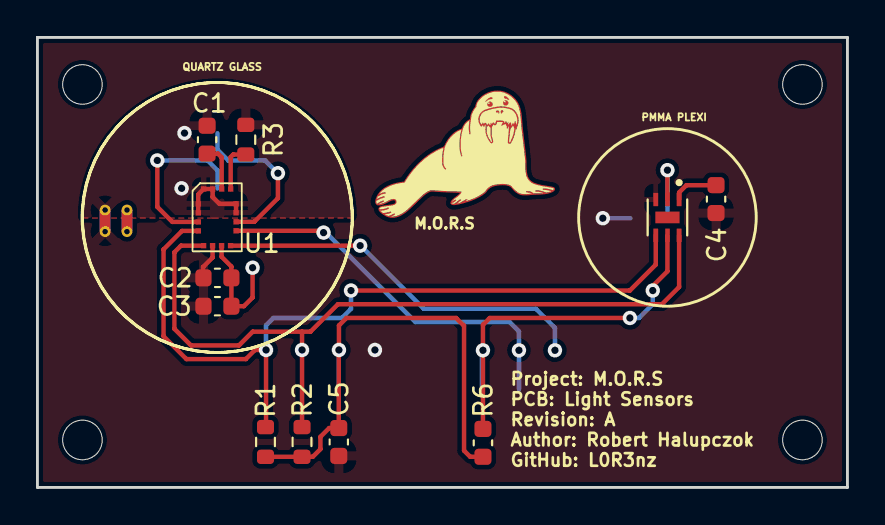
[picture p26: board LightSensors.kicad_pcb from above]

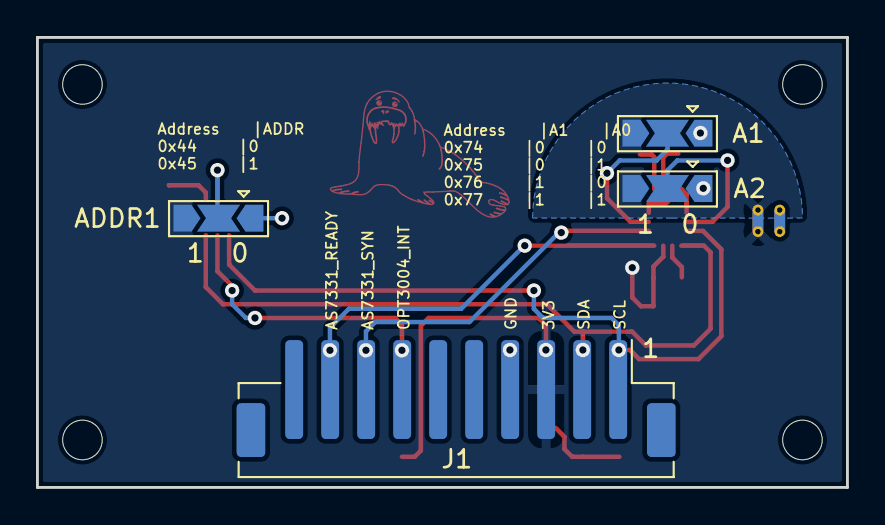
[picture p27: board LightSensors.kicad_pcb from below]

Board: 2 copper layers, 45.0 x 25.0 mm, 21 parts (5 on the bottom side), 13 nets.

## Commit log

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2023-07-17 Add schematic for Sensor PCB
    [EnviromentSensors.kicad_pcb, EnviromentSensors.kicad_sch]
2023-07-17 Change pullup resistor from 10k to 4.7k
    [EnviromentSensors.kicad_sch]
2023-07-17 Fill revision and schematic date fields
    [EnviromentSensors.kicad_sch]
2023-07-17 Add Power flag to solve ECR errors
    [EnviromentSensors.kicad_sch]
2023-07-17 Assign footprint for schematic elements
    [EnviromentSensors.kicad_sch]
2023-07-17 Add 3d Models for sensors
    [BME680.STEP, LPS22HB.STEP, SHT45.STEP]
2023-07-19 Add initial bord file
    [EnviromentSensors.kicad_pcb]
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2023-07-21 Change resistors and capasitors footprint from 0201 to 0402
    [EnviromentSensors.kicad_sch]
2023-07-21 Add initial version of Enviromental Sensors PCB
    [EnviromentSensors.kicad_pcb]
2023-07-22 Add LCSC part numbers for electronic components
    [EnviromentSensors.kicad_sch]
2023-07-22 Update 3d models for sensors
    [EnviromentSensors.kicad_pcb]
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2023-07-23 Add FreeCAD file with PCB model
    [FreeCAD_PCB_EnviromentSensors.FCStd]
2023-07-28 Create KiCad project for LightSensors PCB
    [LightSensors.kicad_pcb, LightSensors.kicad_sch]
2023-07-28 Import Schematic and PCB settings from EnviromentSensors Board
    [LightSensors.kicad_pcb]
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2023-07-28 Add basic schematic version
    [LightSensors.kicad_sch]
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2023-07-28 Add OPT3004 into schematic
    [LightSensors.kicad_sch]
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2023-07-30 Add connector for LightSensors board
    [EnviromentSensors.kicad_sch]
2023-07-30 Update PCB by adding connector for LightSensors board
    [EnviromentSensors.kicad_pcb]
2023-07-30 Update schematic for LightSensors PCB
    [LightSensors.kicad_sch]
2023-07-30 Change connector to JST PH 2.0
    [LightSensors.kicad_sch]
2023-07-30 Add update PCB dimension
    [LightSensors.kicad_pcb]
2023-07-30 Change Ambient light sensor and fix spelling
2023-07-30 Rename Environmental Sensors board due to spelling
    [EnvironmentSensors.kicad_pcb, EnvironmentSensors.kicad_sch]
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2023-07-30 Update 3d model of Environment Sensors PCB
    [FreeCAD_PCB_EnvironmentSensors.FCStd]
2023-07-30 Update PCB for LightSensors
    [LightSensors.kicad_pcb]
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2023-08-05 Add SF2 filter to schematic
    [EnvironmentSensors.kicad_sch]
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2023-08-05 Create InnerSection of solar radiation shield for sensors
    [RadiationShield_InnerSection.FCStd]
2023-08-05 Add InnerSection stl file
    [RadiationShield_InnerSection-Body.stl]
2023-08-05 Create InnerSection whitch holds PCB
    [RadiationShield_PCB_Section.FCStd]
2023-08-05 Add PCB holder section STL file
    [RadiationShield_PCB_Section-Body.stl]
2023-08-05 Create TopSection of solar radiation shield for sensors
    [RadiationShield_TopSection.FCStd]
2023-08-05 Add TopSection STL file
    [RadiationShield_TopSection-Body.stl]
2023-08-05 Create BottomSection of solar radiation shield for sensors
    [RadiationShield_BottomSection.FCStd]
2023-08-05 Add BottomSection STL file
    [RadiationShield_BottomSection-Body.stl]
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2023-08-05 Add Assembly STL file
    [RadiationShield_Assembly-Part.stl]
2023-08-14 modify top section of radfiation shield to have initial dimentions od light sensor PCB
    [RadiationShield_TopSection.FCStd]
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2023-08-14 Design initial version of PCB for light sensors
    [LightSensors.kicad_pcb]
2023-08-14 Update assembly to check collisions
    [RadiationShield_Assembly.FCStd]
2023-08-20 Add signal names on silkscreen and add connector 3dmodel
    [LightSensors.kicad_pcb]
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2023-08-20 Update pcb due to connector pinout fix
    [LightSensors.kicad_sch]
2023-08-20 Change footprint for connectors
    [EnvironmentSensors.kicad_sch]
2023-08-20 Update pcb due to conector change
    [EnvironmentSensors.kicad_pcb]
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2023-08-27 Add project logo and update silkscreen
    [EnvironmentSensors.kicad_pcb]
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2023-08-27 Fix 10mm footprint logo
2023-08-27 Add logo into pcb and update silkscreen
    [LightSensors.kicad_pcb]
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2023-08-27 Add back cover for top shield to improve moisture resistance
    [RadiationShield_TopSection_Back.FCStd]
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2023-08-27 Update STL file for Top section
    [RadiationShield_TopSection-Body.stl]
2023-08-27 Add STL file for new top section back cover
    [RadiationShield_TopSection_Back-Body.stl]
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2023-09-02 Add capacitor for supply connector, SHT21 and change resistors and capacitors footprint to 0603
    [EnvironmentSensors.kicad_sch]
2023-09-02 Update layout with changes made in schematic
    [EnvironmentSensors.kicad_pcb]
2023-09-02 Change footprints for resistors, capasitors and change mounting holes to M2
    [LightSensors.kicad_sch]
2023-09-03 Add capacitor bettwen VCC and GND, Update schematic date
    [LightSensors.kicad_sch]
2023-09-03 Add capacitor bettwen VCC and GND on PCB
    [LightSensors.kicad_pcb]
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2023-09-03 Add missing 3d model of lightSensors pcb
    [FreeCAD_PCB_LightSensors.FCStd, FreeCAD_PCB_LightSensors.stl, LightSensors.kicad_pcb]
2023-09-03 Update 3d model of environmental sensors pcb
    [FreeCAD_PCB_EnvironmentSensors.FCStd, FreeCAD_PCB_EnvironmentSensors.stl]
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2023-09-03 Pre release environmental sensors PCB
    [EnvironmentSensors.kicad_pcb]
2023-09-03 Pre release light sensors PCB
    [LightSensors.kicad_pcb]
2024-02-18 Update top element of the radiation sheield
    [RadiationShield_TopSection.FCStd]
2024-02-18 Update STL file for top section of radiation shield
    [RadiationShield_TopSection-Body.stl]
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2024-08-14 Add stencil holder tool to improve soldering proccess
    [EnvironmentSensors_ Stencil_Holder-Body.stl, EnvironmentSensors_ Stencil_Holder.FCStd]
